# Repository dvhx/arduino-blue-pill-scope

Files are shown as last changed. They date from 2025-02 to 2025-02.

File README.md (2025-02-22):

# arduino-blue-pill-scope
860kSPS USB scope made from Blue Pill using Arduino IDE

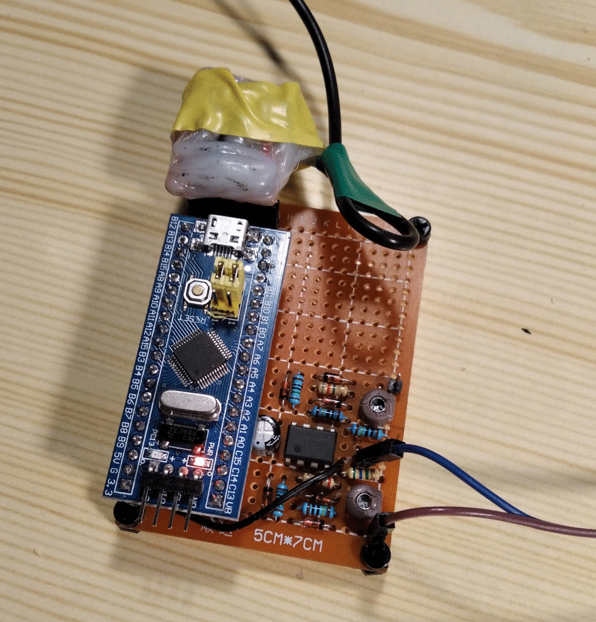
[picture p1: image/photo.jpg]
perfboard photo

(this version have only first 2 voltage ranges populated)

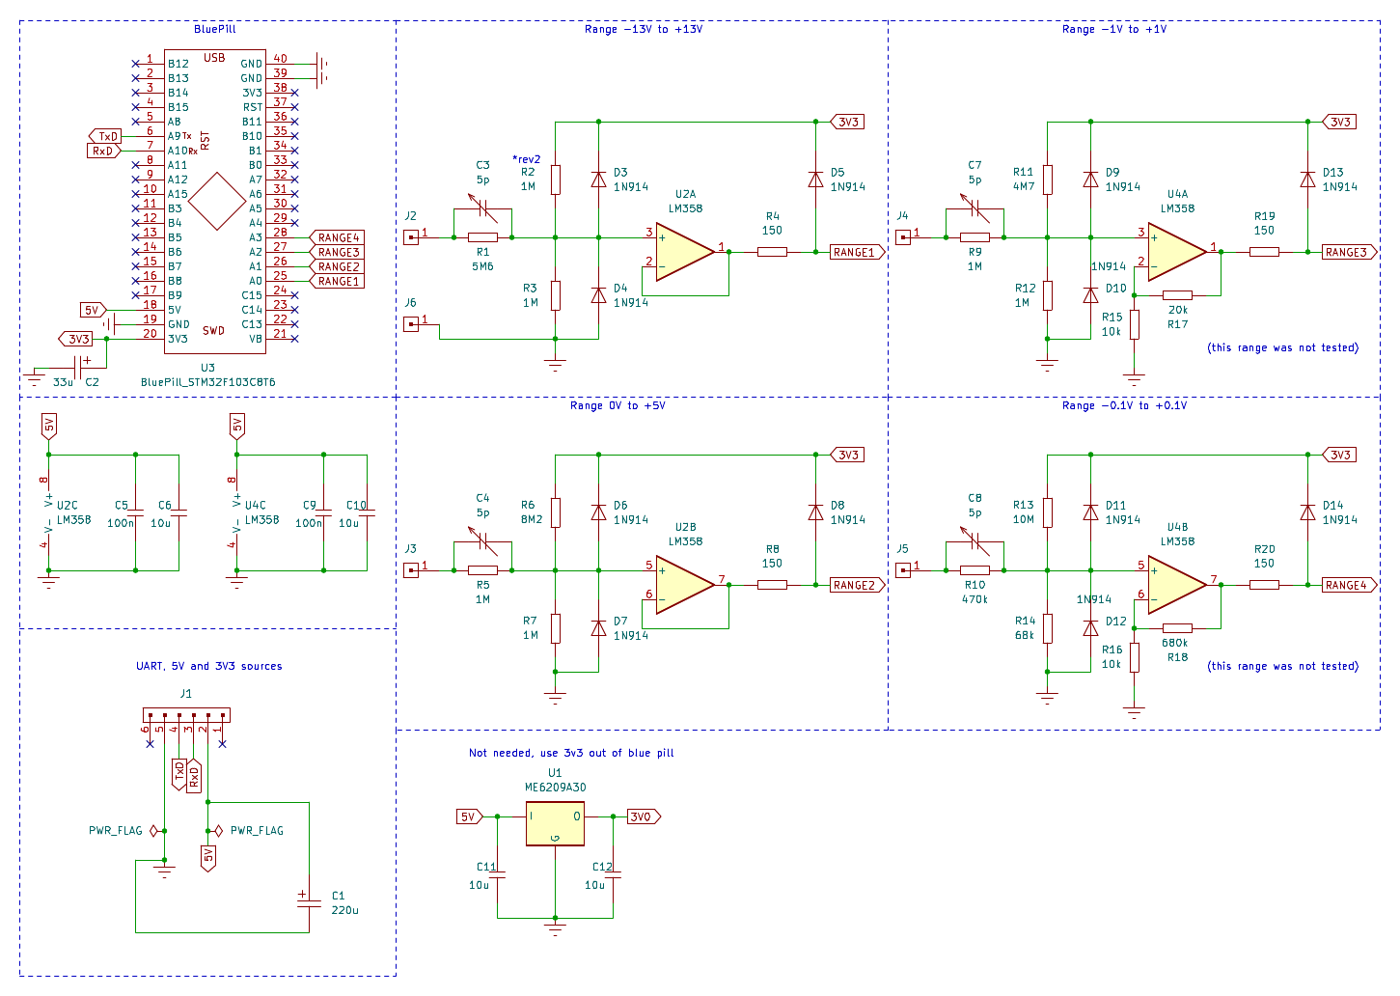
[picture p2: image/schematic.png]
schematic


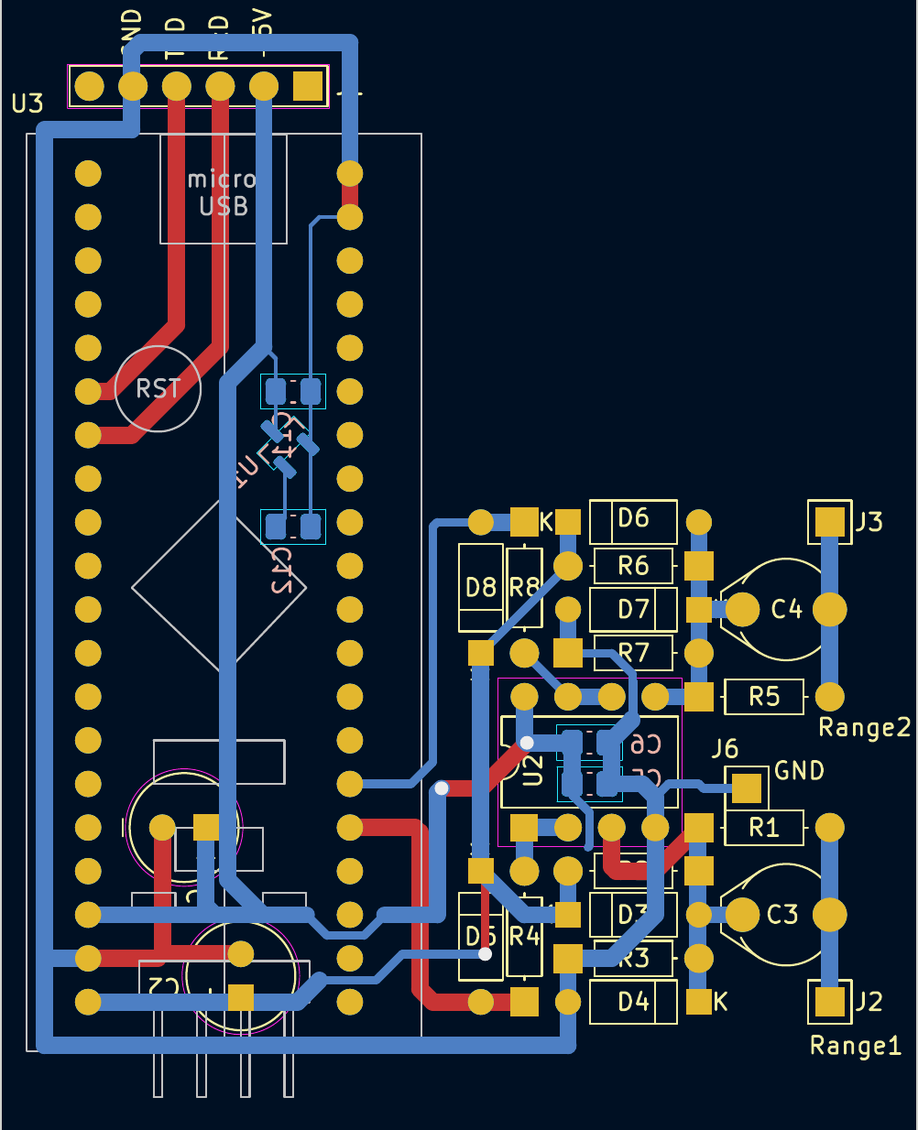
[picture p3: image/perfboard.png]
perfboard


I also made App in lazarus that interfaces the scope and shows curves:

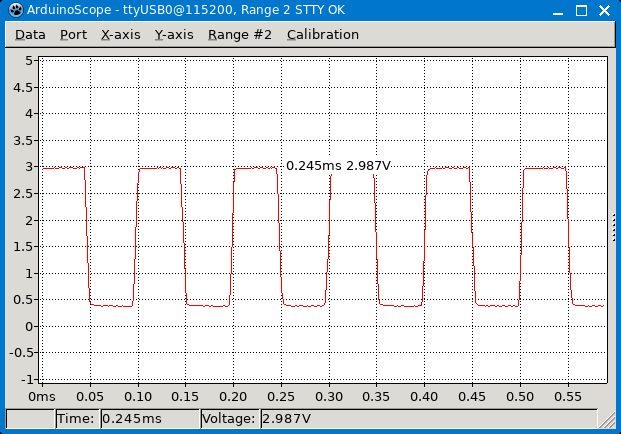
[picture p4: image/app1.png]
App


# Revisions

1. First working 860kSPS DMA but dividers were unwisely plced on 5V rail which real world USB cables and 30mA of F103 pulled down to 4.6 and not in a nice consistent way, the noise was around 100mV, it was unusable.
2. Dividers moved to 3V3 rail which stabilized it, some resistor values needed to be adjusted to get output back into ADC range. Added app.

# Conclusion

It works, it's usable, it's more stable than DSO-138. If I were to make a PCB or version 2.0 I would choose STM variant that has separate analog ground and separate vref pin.

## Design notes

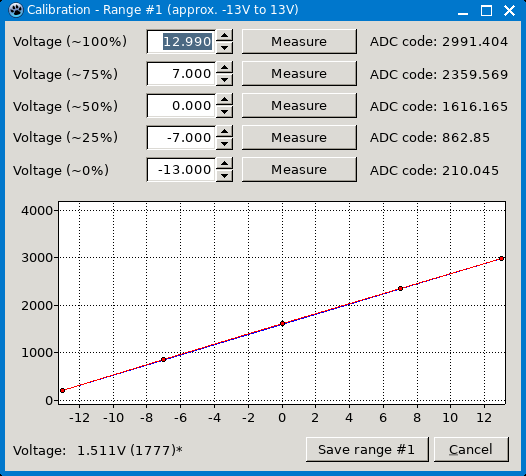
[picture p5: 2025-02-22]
image/app2.png

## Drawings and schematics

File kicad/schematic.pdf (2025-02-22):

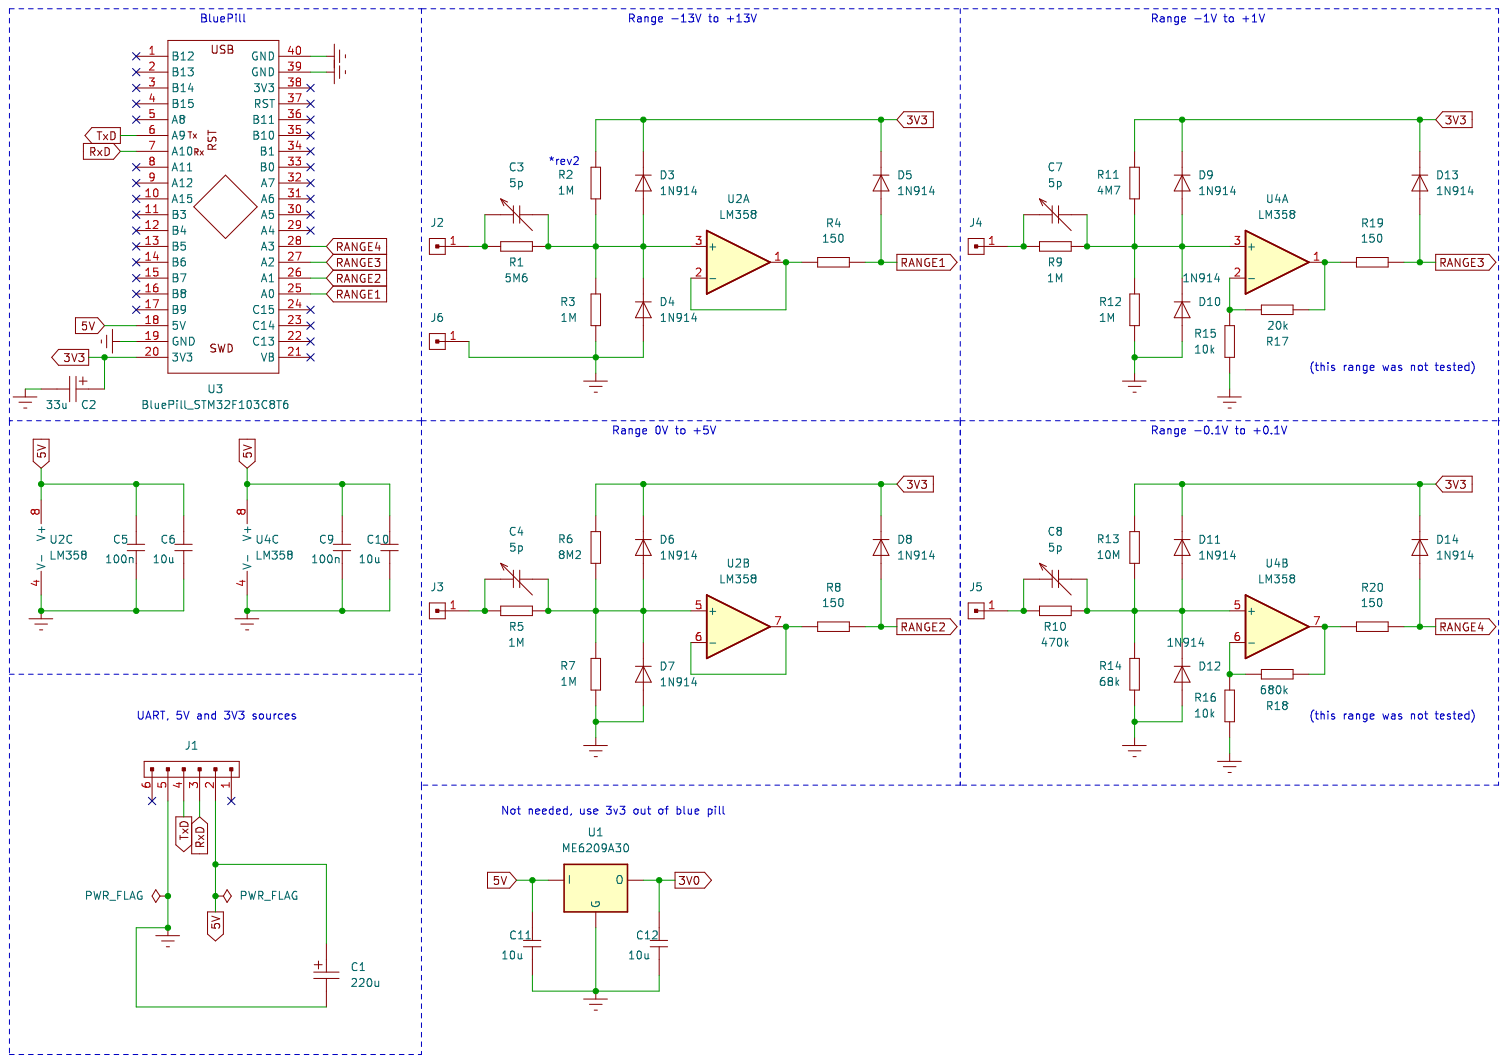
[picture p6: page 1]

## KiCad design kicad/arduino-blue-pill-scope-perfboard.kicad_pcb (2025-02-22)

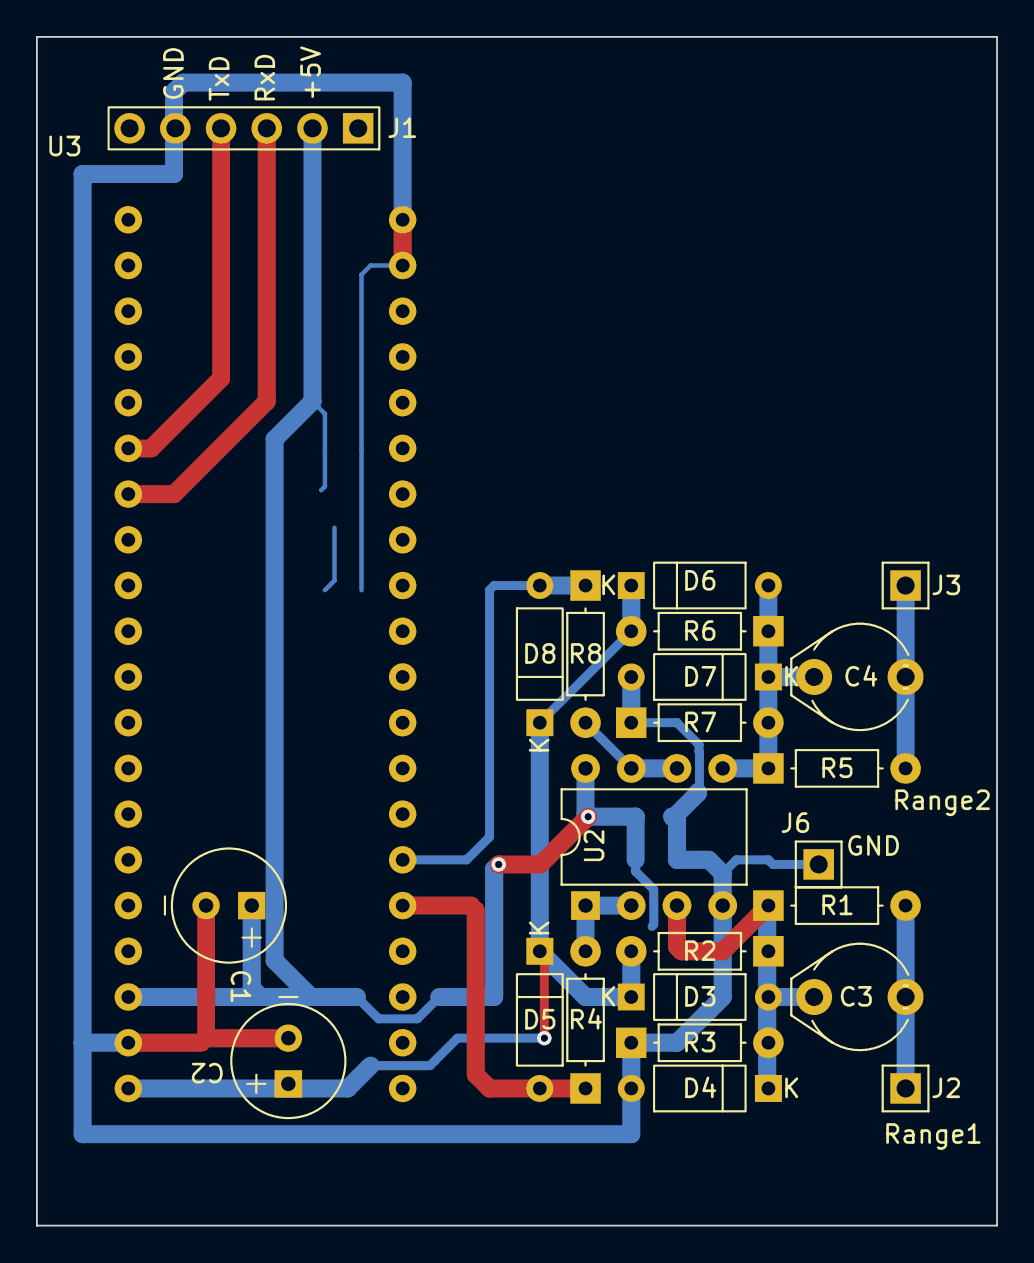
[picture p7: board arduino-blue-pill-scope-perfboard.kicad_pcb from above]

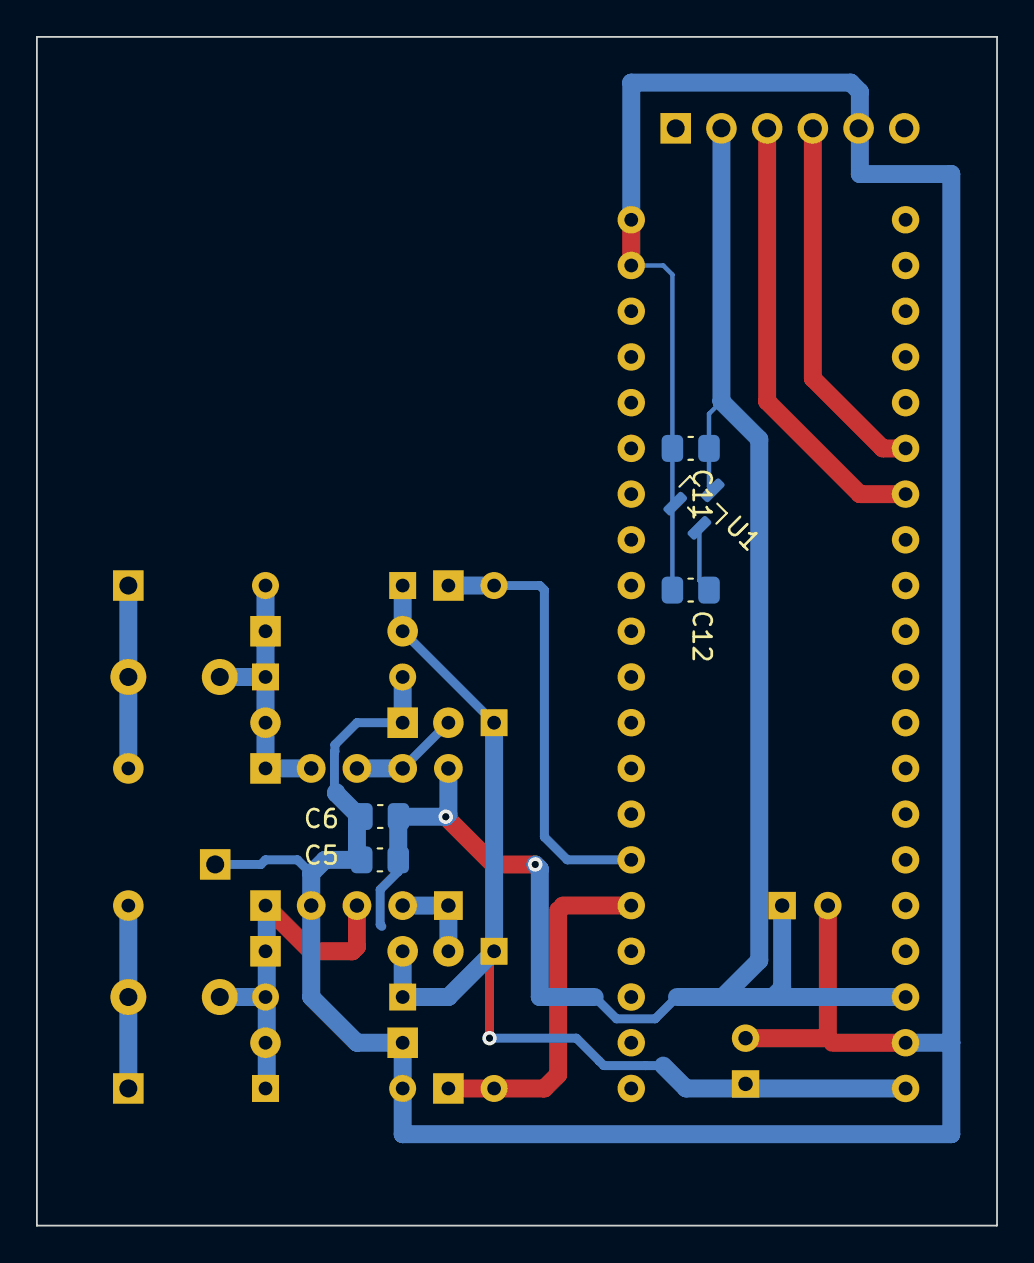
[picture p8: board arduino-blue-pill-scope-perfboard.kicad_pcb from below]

Board: 4 copper layers, 53.3 x 66.0 mm, 29 parts (5 on the bottom side), 14 nets.

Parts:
C1: 220u; C_polarized_D6.35mm_H5.65mm_P2.54mm
C2: 33u; C_polarized_D6.35mm_H5.65mm_P2.54mm
C3, C4: 5p; C_variable
C5: 100n; C_0805
C6, C11, C12: 10u; C_0805
D3, D4, D5, D6, D7, D8: 1N914; D_DO-41
J1: Header_1x6_male; Header_1x6_male_upright
J2, J3, J6: Header_1x1_male; Header_1x1_male_upright
R1: 5M6; R_0.25W
R2, R3, R5, R7: 1M; R_0.25W
R4, R8: 150; R_0.25W
R6: 8M2; R_0.25W
U1: ME6209A30; SOT23-GOI
U2: LM358; DIP-8_W7.62mm
U3: BluePill_STM32F103C8T6

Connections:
3V0: C12.1, U1.O
3V3: C2.P, D3.K, D5.K, D6.K, D8.K, R2.2, R6.2, U3.20 (3V3)
5V: C1.P, C5.1, C6.1, C11.1, J1.2, U1.I, U2.8 (V+), U3.18 (5V)
GND: C1.N, C2.N, C5.2, C6.2, C11.2, C12.2, D4.A, D7.A, J1.5, J6.1, R3.1, R7.1, U1.G, U2.4 (V-), U3.19 (GND), U3.39 (GND), U3.40 (GND)
unnamed: C3.1, J2.1, R1.2
unnamed: C3.2, D3.A, D4.K, R1.1, R2.1, R3.2, U2.3 (+)
unnamed: C4.1, J3.1, R5.2
unnamed: C4.2, D6.A, D7.K, R5.1, R6.1, R7.2, U2.5 (+)
unnamed: R4.2, U2.1, U2.2 (-)
unnamed: R8.2, U2.6 (-), U2.7
RANGE1: D5.A, R4.1, U3.25 (A0)
RANGE2: D8.A, R8.1, U3.26 (A1)
RxD: J1.3, U3.7 (A10)
TxD: J1.4, U3.6 (A9)

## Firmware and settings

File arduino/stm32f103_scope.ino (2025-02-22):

// Read 12bit ADC samples from pin PA0 of STM32F103C8T6 (blue pill) at 800kHz using DMA
// Tested on BluePill F103C8

#include "stm32f1xx.h"
#include "stm32f1xx_hal_def.h"

// number of samples
#define BUF_SIZE 500
uint16_t buffer[BUF_SIZE];

ADC_HandleTypeDef hadc1;
DMA_HandleTypeDef hdma_adc1;

inline void Serial_write16(uint16_t value) {
  // Send single uint16_t
  Serial.write((value >> 8) & 0xFF);
  Serial.write(value & 0xFF);
}

uint32_t currentSamplingTime = ADC_SAMPLETIME_1CYCLE_5;
uint32_t currentChannel = ADC_CHANNEL_0;

void MX_ADC1_Init() {
  // Configure ADC1
  hadc1.Instance = ADC1;
  hadc1.Init.ScanConvMode = ADC_SCAN_DISABLE;
  hadc1.Init.ContinuousConvMode = ENABLE;
  hadc1.Init.DiscontinuousConvMode = DISABLE;
  hadc1.Init.ExternalTrigConv = ADC_SOFTWARE_START;
  hadc1.Init.DataAlign = ADC_DATAALIGN_RIGHT;
  hadc1.Init.NbrOfConversion = 1;
  if (HAL_ADC_Init(&hadc1) != HAL_OK) {
    Serial.println("HAL_ADC_Init() failed!");
    return;
  }
    
  // Configure Regular Channel
  ADC_ChannelConfTypeDef sConfig = {0};
  sConfig.Channel = currentChannel; //ADC_CHANNEL_0;
  sConfig.Rank = ADC_REGULAR_RANK_1;
  sConfig.SamplingTime = currentSamplingTime;
  //ADC_SAMPLETIME_239CYCLES_5;
  //sConfig.SamplingTime = ADC_SAMPLETIME_13CYCLES_5;
  //sConfig.SamplingTime = ADC_SAMPLETIME_7CYCLES_5;
  //sConfig.SamplingTime = ADC_SAMPLETIME_1CYCLE_5;
  if (HAL_ADC_ConfigChannel(&hadc1, &sConfig) != HAL_OK){
    Serial.println("HAL_ADC_ConfigChannel() failed!");
    return;
  }

  // Configure DMA for ADC1
  __HAL_RCC_DMA1_CLK_ENABLE();
  hdma_adc1.Instance = DMA1_Channel1;
  hdma_adc1.Init.Direction = DMA_PERIPH_TO_MEMORY;
  hdma_adc1.Init.PeriphInc = DMA_PINC_DISABLE;
  hdma_adc1.Init.MemInc = DMA_MINC_ENABLE;
  hdma_adc1.Init.PeriphDataAlignment = DMA_PDATAALIGN_HALFWORD;
  hdma_adc1.Init.MemDataAlignment = DMA_MDATAALIGN_HALFWORD;
  hdma_adc1.Init.Mode = DMA_NORMAL; //DMA_CIRCULAR;
  hdma_adc1.Init.Priority = DMA_PRIORITY_LOW;
  if (HAL_DMA_Init(&hdma_adc1) != HAL_OK) {
    Serial.println("HAL_DMA_Init() failed!");
    return;
  }

  // Link DMA to ADC
  __HAL_LINKDMA(&hadc1, DMA_Handle, hdma_adc1);
}

extern "C" void HAL_ADC_ConvCpltCallback(ADC_HandleTypeDef* hadc) {
  // This should be called at the end of the conversion but it's not
  // for now I know how long it takes to measure samples so I just wait
  Serial.println("adc conversion completed");
  if (hadc->Instance == ADC1) {
    Serial.println("adc1 conversion completed");
  }
}

void analogReadFast(uint16_t* buffer, int size) {
  // read samples into buffer
  // Stop ADC and DMA after reading the first sample
  HAL_ADC_Stop_DMA(&hadc1);
  // Clear the buffer
  for (int i = 0; i < size; i++) {
    buffer[i] = 123;
  }
  // Restart ADC and DMA for the next sample and entire buffer
  if (HAL_ADC_Start_DMA(&hadc1, (uint32_t*)buffer, BUF_SIZE) != HAL_OK) {
    Serial.println("HAL_ADC_Start_DMA() failed!");
    return;
  }
}

void setup() {
  Serial.begin(115200);
  pinMode(PA0, INPUT_ANALOG);
  pinMode(PA7, INPUT_ANALOG);
  // start with PA0
  MX_ADC1_Init();
}

int t1, t2;

void Serial_wait() {
  while (not Serial.available()) {};
}
   
void loop() {
  if (Serial.available()) {
    int c = Serial.read();
   
    // B,block of data
    if (c == 'B') {
      t1 = millis();
      analogReadFast(&buffer[0], BUF_SIZE);
      delay(5);
      for (int i = 0; i < BUF_SIZE; i++) {
        Serial_write16(buffer[i]);
      }
      t2 = millis();
    }
    // Cx - channel switching, x=1..4  (lowercase c is the same but doesn't print anything back)
    if (c == 'C' || c == 'c') {
      Serial_wait();
      int r = Serial.read();
      switch (r) {
        case '1': currentChannel = ADC_CHANNEL_0; break;
        case '2': currentChannel = ADC_CHANNEL_7; break;
        case '3': currentChannel = ADC_CHANNEL_8; break;
        case '4': currentChannel = ADC_CHANNEL_9; break;
      }
      MX_ADC1_Init();
      if (c == 'C') {
        Serial_write16(currentChannel);
      }
    }
    // Sx sample time switching, x=1..8   (lowercase s is the same but doesn't print anything back)
    if (c == 'S' || c == 's') {
      Serial_wait();
      int d = Serial.read();
      switch (d) {
        case '1': currentSamplingTime = ADC_SAMPLETIME_1CYCLE_5; break;
        case '2': currentSamplingTime = ADC_SAMPLETIME_7CYCLES_5; break;
        case '3': currentSamplingTime = ADC_SAMPLETIME_13CYCLES_5; break;
        case '4': currentSamplingTime = ADC_SAMPLETIME_28CYCLES_5; break;
        case '5': currentSamplingTime = ADC_SAMPLETIME_41CYCLES_5; break;
        case '6': currentSamplingTime = ADC_SAMPLETIME_55CYCLES_5; break;
        case '7': currentSamplingTime = ADC_SAMPLETIME_71CYCLES_5; break;
        case '8': currentSamplingTime = ADC_SAMPLETIME_239CYCLES_5; break;
      }
      MX_ADC1_Init();
      if (c == 'S') {
        Serial_write16(d);
      }
    }
    // measure period of a square wave signal
    if (c == 'P') {
      analogReadFast(&buffer[0], BUF_SIZE);
      delay(5);
      // find high and low levels
      int lo = 4096;
      int hi = 0;
      for (int i = 0; i < BUF_SIZE; i++) {
        lo = buffer[i] < lo ? buffer[i] : lo;
        hi = buffer[i] > hi ? buffer[i] : hi;
      }
      int mid = (lo + hi) / 2;
      // find 3 transitions from high to low or low to high
      bool o = buffer[0] < mid ? false : true;
      int i1 = 0, i2 = 0, i3 = 0;
      for (int i = 0; i < BUF_SIZE; i++) {
        bool n = buffer[i] < mid ? false : true;
        if (o != n) {
          if (i1 == 0) {
            i1 = i;
          } else {
            if (i2 == 0) {
              i2 = i;
            } else {
              if (i3 == 0) {
                i3 = i;
                // break; no break to make all frequencies be measured in same time with same delay
              }
            }
          }
        }
        o = n;
      }
      Serial_write16(i3-i1);
    }
    
    // print some debug info
    if (c == 'j') {
      Serial.print("currentSamplingTime=");
      Serial.print(currentSamplingTime);
      Serial.print(" currentChannel=");
      Serial.print(currentChannel);
      Serial.println();
    }

    // A,average code from entire block
    if (c == 'a') {
      analogReadFast(&buffer[0], BUF_SIZE);
      delay(5);
      int s = 0;
      for (int i = 0; i < BUF_SIZE; i++) {
        s += buffer[i];
      }
      Serial_write16((10 * s) / BUF_SIZE);
    }  
    // A,average code from entire block 30 times
    if (c == 'A') {
      float t = 0;
      int repeats = 30;
      for (int r = 0; r < repeats; r++) {
        analogReadFast(&buffer[0], BUF_SIZE);
        delay(5);
        int s = 0;
        for (int i = 0; i < BUF_SIZE; i++) {
          s += buffer[i];
        }
        t += s / BUF_SIZE;
      }
      Serial_write16(10.0 * t / repeats);
    }     
  }
}

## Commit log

2025-02-22 Updated arduino code
2025-02-22 Updated kicad project
    [arduino-blue-pill-scope-perfboard.kicad_pcb, arduino-blue-pill-scope-perfboard.kicad_sch]
